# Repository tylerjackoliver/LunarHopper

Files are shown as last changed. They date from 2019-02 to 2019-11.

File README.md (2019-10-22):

# Lunar Hopper GitHub Repo

This is the repo for the Lunar Hopper on-board computer and control system.

## Test script usage
Tester file format:
*time (seconds) | command | arguments*

Tester file example:
```
0 start high
0.01 gyro 1 2
0.05 accel 1 2 3
0.1 throttle 50
0.27 press 90
1 abort high
5 disarm high
10 end
```

Test file example output:
```
-0.08030: ACT_PIN_X_POS reads 0
-0.08025: ACT_PIN_X_NEG reads 0
-0.08022: ACT_PIN_Y_POS reads 0
-0.06462: ACT_PIN_Y_NEG reads 0
-0.06457: SOL_PIN_VENT reads 0
-0.03106: SOL_PIN_PRES reads 0
-0.03098: SOL_PIN_OX reads 0
0.000371: 0 start high
0.012370: 0.01 gyro 1 2
0.085079: 0.05 accel 1 2 3
0.108033: 0.1 throttle 50
0.326400: 0.27 press 90
1.030022: 1 abort high
5.057830: 5 disarm high
10.06733: 10 end
10.10730: Test has concluded
```

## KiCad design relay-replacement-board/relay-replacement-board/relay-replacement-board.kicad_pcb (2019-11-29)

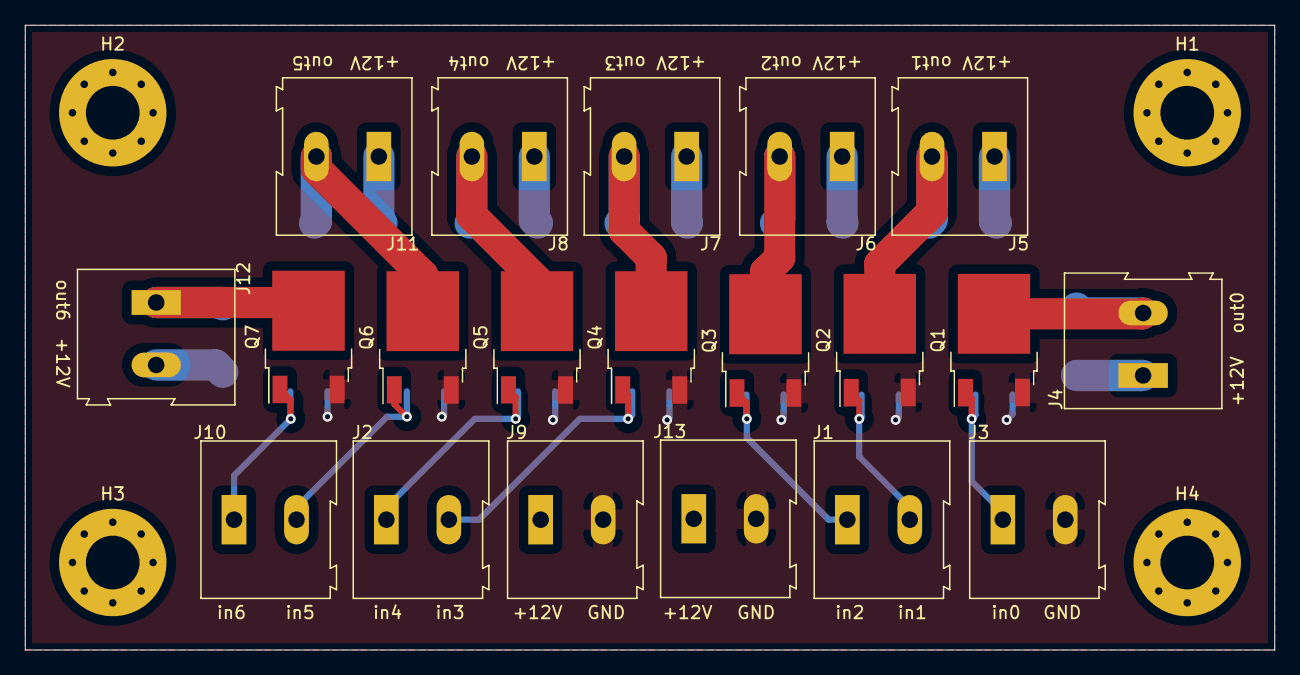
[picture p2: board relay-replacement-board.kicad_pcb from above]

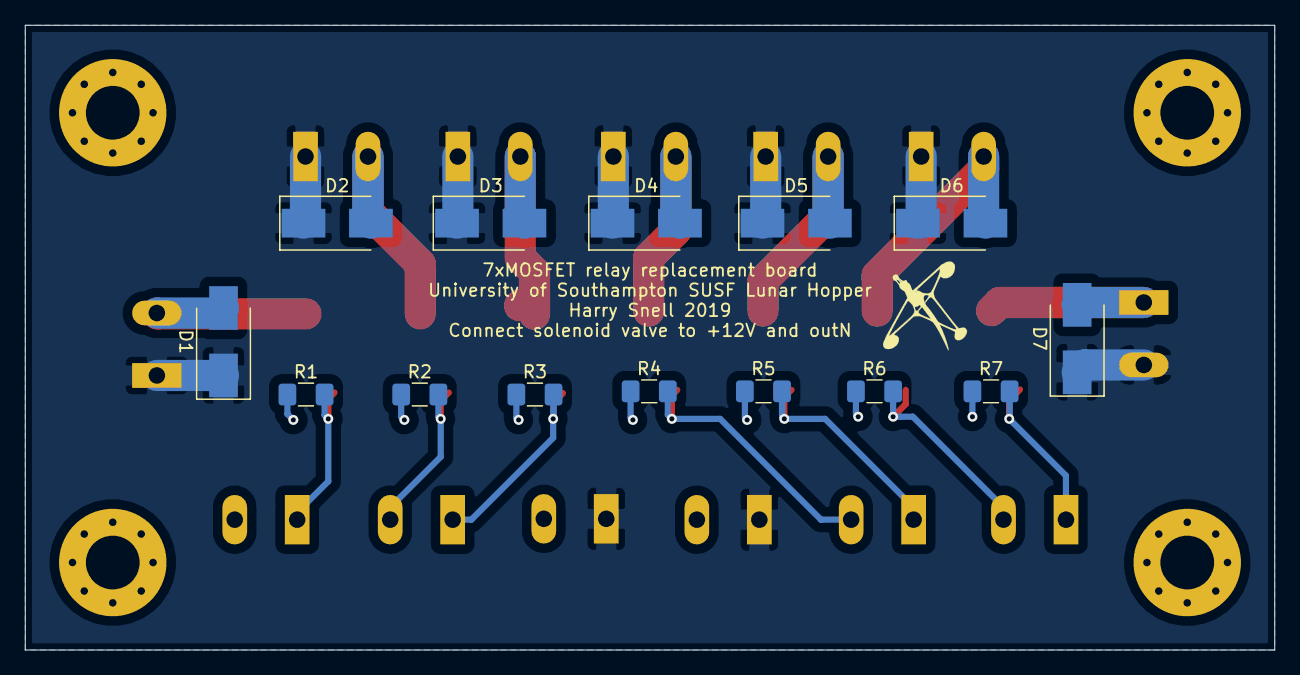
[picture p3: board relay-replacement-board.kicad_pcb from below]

Board: 2 copper layers, 100.0 x 50.0 mm, 38 parts (14 on the bottom side), 16 nets.

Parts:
D1, D2, D3, D4, D5, D6, D7: D; D_SMB_Handsoldering
H1, H2, H3, H4: MountingHole_4.3mm_M4_Pad_Via
J1, J2, J3, J4, J5, J6, J7, J8, J9, J10, J11, J12, J13: Conn_01x02; TerminalBlock_Altech_AK300-2_P5.00mm
Q1, Q2, Q3, Q4, Q5, Q6, Q7: NVD5865NL; TO-252-2
R1, R2, R3, R4, R5, R6, R7: 10K; R_1206_3216Metric_Pad1.42x1.75mm_HandSolder

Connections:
+12V: D1.1, D2.1, D3.1, D4.1, D5.1, D6.1, D7.1, J4.1, J5.1, J6.1, J7.1, J8.1, J9.1, J11.1, J12.2, J13.1
/trigger0: J3.1, Q1.1, R1.2
/trigger1: J1.2, Q2.1, R2.2
/trigger2: J1.1, Q3.1, R3.2
/trigger3: J2.2, Q4.1, R4.2
/trigger4: J2.1, Q5.1, R5.2
/trigger5: J10.2, Q6.1, R6.2
/trigger6: J10.1, Q7.1, R7.2
GND: J3.2, J9.2, J13.2, Q1.3, Q2.3, Q3.3, Q4.3, Q5.3, Q6.3, Q7.3, R1.1, R2.1, R3.1, R4.1, R5.1, R6.1, R7.1
unnamed: D1.2, J4.2, Q1.2
unnamed: D2.2, J5.2, Q2.2
unnamed: D3.2, J6.2, Q3.2
unnamed: D4.2, J7.2, Q4.2
unnamed: D5.2, J8.2, Q5.2
unnamed: D6.2, J11.2, Q6.2
unnamed: D7.2, J12.1, Q7.2

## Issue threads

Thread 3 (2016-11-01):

Rename Pins

bigboateng, 2016-11-01:
need to change the un-named pins when we know what they do. [Check this file](https://github.com/tylerjackoliver/LunarHopper/blob/master/Mk2.1_hopper_control.ino#L193-198)

tylerjackoliver, 2016-11-01:
Unnamed pins were renamed in commit c3c12a11de7ddbf1ebb9072c8c89a552c9bad47e.

bigboateng, 2016-11-01:
1. On the [Master Branch](https://github.com/tylerjackoliver/LunarHopper/blob/master/Mk2.1_hopper_control.ino#L193-198), the change is not there, which branch was that commit in?
2. Maybe we should actually rename the pins as variables because its still not clear what testing pins that is.

tylerjackoliver, 2016-11-01:
You're correct; the pins were commented out in the setup() of c3c12a11de7ddbf1ebb9072c8c89a552c9bad47e. Need to go through master and remove all references to pins 7, 8, 9, 24, 26, 28 as they are obsolete.

tylerjackoliver, 2016-11-01:
Need to verify code is still working after removing pin unnecessary pin references in commit cf2e08ffbd0063617e6673bff230312deaae3e4f in branch RemovedPins.

duncanrhamill, 2016-11-01:
Pins 7, 8 & 9 might be used for testing the ox pulse onto the catalyst bed, need to verify if they're needed in flight or just in test.

tylerjackoliver, 2016-11-02:
I spoke with Marian, who wrote the code: we had the right purpose for the pins and were correct to remove them in commit cf2e08ffbd0063617e6673bff230312deaae3e4f.

bigboateng, 2016-11-02:
So is this issue settled then? @tylerjackoliver

Closed 2016-11-02.

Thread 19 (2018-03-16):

Determine desired telemetry to design structure for a standard telemetry packet

tylerjackoliver, 2018-03-16:
To work on: https://github.com/tylerjackoliver/LunarHopper/projects/2#card-8045901

I'm going to take a look through the paperwork, and see exactly what telemetry we actually need back (or rather, what telemetry would be useful for debugging vehicle performance). That should let us know how long our packets need to be, and we can work on this from there.

cc: @shane-lawson

tylerjackoliver, 2018-03-16:
After going on a caffeine-fueled adventure, I think the only data we care about is the one that gives us our deltas from nominal performance, to be able to feedback into the ideal design spec. To that end, I think definitely we need to recover current pressure (if we are controlling it remotely, saving the pressure we set as well, or if it's on board, perhaps also grab desired pressure, so we can work out steady state errors and residual thrust problems), and also gyro rates. The current status of the vehicle also might be quite nice, i.e. ARM_HIGH, MECO_ON etc -- we can always dedicate a portion of each packet just to 1's and 0's that decide these values.

Just my first $.02...

shane-lawson, 2018-03-16:
100% agree with you about status of the various states, I was already thinking about maybe a byte or two header of bit values for on/off of various states.

For now I'll look at supporting:

- [ ] one byte with states
- [ ] current pressure value
- [ ] pressure set point
- [ ]     gyro rates
- [ ]     accel values (for good measure)

shane-lawson, 2018-11-01:
I initially created the branch `add-telemetry` to do this and I figured how everything worked. That code was really convoluted, so I forked `add-telemetry-final` from 58bd686a13075b064b94ddcac70d687cc5ce84ae as nothing after that commit in `add-telemetry` was useful anymore. This makes the `add-telemetry` branch functionally dead. I didn't merge it or rebase it onto `add-telemetry-final` as I thought that would make for a confusing history, so instead we'll probably just delete the `add-telemetry` branch.

In terms of accomplishing the above, the code currently just sends a single byte. I guess I never managed to create the logic for sending a string of bytes with all the above values. I plan on finishing that part and supporting all 5 things above. The `add-telemetry-final` branch is currently up-to-date, and I plan to make some nice documentation for it so others can make sense of how the telemetry transmission works, and how to set up an Arduino with an Xbee module to use this.

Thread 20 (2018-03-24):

Cross-check control laws

tylerjackoliver, 2018-03-24:
So, it seems that the control law that is currently implemented is a bit faulty with the angle determination, more than likely as a result of a badly-coded formula somewhere. AFAIK, it doesn't seem like the control laws were ever tuned either, given the '# this may need tweaking!!!'

@shane-lawson how feasible is it to just grab the quaternion/euler angles from the DMP on the 6050 and just plug this straight into their code in lieu of their angle determination code? A brief look at i2cdevlib seems to give the idea it's quite painless.

shane-lawson, 2018-03-24:
If all the DMP configuration code in that library works as specified, then we can _easily_ offload all the computation to the DMP and just pull the angles, etc. directly. I'm hesitant to ensure that this can be done easily, as there always seem to be finicky issues with things such as this that cause issues, the more simple appearing even more so.

The majority of the control code is doing the angle determination, there's just a gain or two that comes through fro the actual control. Pending a further review, we might determine it is easier to just implement, from scratch, the control law explored in the report using the DMP data.

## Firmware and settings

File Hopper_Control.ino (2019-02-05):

/*-------------------------------

Lunar Hopper Control System Code

Written by: Marian Daogaru, mn2g12

Updated by: Samuel Rowbotham      sjr1g18
            Jack Tyler            jt6g15
            Duncan Hamill         dh2g15
            Boateng Opoku-Yeboah  boy1g15
            Shane Lawson          sdl1n17
---------------------------------
*/

#include "Hopper_Control_Classes.cpp"

/*
 * DECLERATIONS
 */

/* PIN NUMBERS
 * Set pins for various input and output devices on arduino. e.g.- gyro, accelerometer,pressure transducer and solenoid valves.
 */
// Sensors (INPUTS)
const int PRES_TRANS_PIN = A4;  // Input from Pressure Transducer [ANALOG]
const int GYRO_PIN_X = A0;      // x-axis Gyro is connected to analog pin
const int GYRO_PIN_Y = A5;      // y-axis gyro
const int ACCEL_PIN_X = A1;     // x-axis accelerometer pin
const int ACCEL_PIN_Y = A2;     // y-axis accelerometer pin
const int ACCEL_PIN_Z = A3;     // z-axis accelerometer pin

// Actuators (OUTPUTS)
const int ACT_PIN_X_POS = 6;    // ACS valve positive x_axis
const int ACT_PIN_X_NEG = 5;    // ACS valve negative x_axis
const int ACT_PIN_Y_POS = 4;    // ACS valve positive y_axis
const int ACT_PIN_Y_NEG = 3;    // ACS valve negative y_axis
const int SOL_PIN_VENT = 12;    // Output to VENT solenoid control (SV2)
const int SOL_PIN_PRES = 10;    // Output to PRESSURE solenoid control (SV1)
const int SOL_PIN_OX = 11;      // Output to OX solenoid control(SV3)

// Control pins (INPUTS)
const int START_PIN = 30;
const int ABORT_PIN = 2;
const int DISARM_PIN = 1; // New pin to be added possibly
const int THROTTLE_PIN = A6;

// Valve constants for readability
const int VALVE_OPEN = HIGH;
const int VALVE_CLOSE = LOW;

/*
 * ACS
 */

// ACS configuration
unsigned long timeZG = 0;                      // Variable to record the start time of zeroing the gyros
unsigned long timeAcs = 0;                     // Variable used to record the start time of each ACS() loop
bool acsInCalibration = false;                 // Tracking variable to detect if ACS subsystem is active
bool acsCalibrated = false;                    // Tracking variable to record if ACS system has been acsCalibrated
bool midCycle = false;                         // Tracking variable to record if ACS system is mid Cycle

/*
 *  Main Engine
 */
// General
const float IGNITION_PRESSURE = 21.0; // bar (abs)
bool pressurised = false; // Records if the engine has been pressurised
bool ignited = false; // Records if the engine has been ignited

// oxPulse specific
int blipMode = 0;                            // Records the current mode of the oxPulse function (0: Ready to fire another blip, 1: Just fired a blip, 2: Just rested after a blip)
int oxPulseNo = 0;                           // Records the number of oxygen pulses completed (In Ignition)
unsigned long timePulse = 0;                 // Records the start time of the last ox blip


/*
 * System status
 * Used to record the current state of the hopper
 */
bool startStatus = false;                   // Records the state of the start pin to start the flight
bool disarmStatus = false;                  // Stores if the hopper has been disarmed
bool abortStatus = false;                   // Stores if the hopper has aborted
double currentPressure = 0;                 // Current pressre of the pressure transducer

// Initialisation of objects.
Accelerometer accelerometer;                // The accelerometers
Gyro gyro;                                  // The gyros
/*
 * CODE
 */

// Setup Loop
void setup() {
  Serial.begin(9600);
  Serial.println("Starting serial process...");
  pinMode(START_PIN, INPUT);      // Defines the Start pin as an INPUT
  pinMode(ABORT_PIN, INPUT);      // Defines the Abort pin as an INPUT
  pinMode(DISARM_PIN, INPUT);     // Defines the Disarm pin as an INPUT
  pinMode(THROTTLE_PIN, INPUT);   // Defines the Throttle as an INPUT
  pinMode(PRES_TRANS_PIN, INPUT); // Defines the Pressure Transducer reading as an INPUT
  pinMode(GYRO_PIN_X, INPUT);     // Defines the Gyro X reading as an INPUT
  pinMode(GYRO_PIN_Y, INPUT);     // Defines the Gyro Y reading as an INPUT
  pinMode(ACCEL_PIN_X, INPUT);    // Defines the Accelerometer X reading as an INPUT
  pinMode(ACCEL_PIN_Y, INPUT);    // Defines the Accelerometer Y reading as an INPUT
  pinMode(ACCEL_PIN_Z, INPUT);    // Defines the Accelerometer Z reading as an INPUT
  pinMode(ACT_PIN_X_POS, OUTPUT); // Defines the ACT positive X as an OUTPUT
  pinMode(ACT_PIN_X_NEG, OUTPUT); // Defines the ACT negative X as an OUTPUT
  pinMode(ACT_PIN_Y_POS, OUTPUT); // Defines the ACT positive Y as an OUTPUT
  pinMode(ACT_PIN_Y_NEG, OUTPUT); // Defines the ACT negative Y as an OUTPUT
  pinMode(SOL_PIN_VENT, OUTPUT);  // Defines the signal to Vent control as an OUTPUT
  pinMode(SOL_PIN_PRES, OUTPUT);  // Defines the signal to Pressure control as an OUTPUT
  pinMode(SOL_PIN_OX, OUTPUT);    // Defines the signal to OX control as an OUTPUT

  accelerometer.setPins(ACCEL_PIN_X,ACCEL_PIN_Y,ACCEL_PIN_Z);
  gyro.setPins(GYRO_PIN_X,GYRO_PIN_Y);
}

/*
 * Main execution loop
 */

void loop() {
  Serial.print("In loop:   ");
  Serial.println(timeZG);

  if (abortStatus == false) {
    Serial.println("ABORT status = false");
    if (disarmStatus == false) {
      if (startStatus == true) {
        Serial.println("Start = true");

        if (acsCalibrated == false) {
          Serial.println("Performing calibration...");
          acsCalibration();

        } else if (ignited == false) {
          Serial.print("oxPulseNo = ");
          Serial.println(oxPulseNo);
          oxPulse();
          
        } else {
          Serial.println("acs...");
          acs();
          Serial.println("throttle...");
          throttle();

        }
      } else {
        startStatus = digitalRead(START_PIN);
        Serial.println("Reading start pin...");

      }
      if (disarmStatus == false){ // Prevents disarm status from being overwritten
        disarmStatus = digitalRead(DISARM_PIN);

      }
      Serial.print("disarm status = ");
      Serial.println(disarmStatus);
    } else {
      disarm();

    }
  } else {
    abort();

  }
  if (abortStatus == false){ // Prevents abort status from being overwritten
      abortStatus = digitalRead(ABORT_PIN);

  }
  Serial.print("abort status = ");
  Serial.println(abortStatus);
}
  

/*
 * UPDATED TO LATEST VERSION 20/11/18 by Samuel Rowbotham
 *  Not Verified through system tests/simulations.
 *  Will slowly disarm the vehicle by having a gap between meco and ventAct
 */
void disarm() {
  const int ACT_VENT_DELAY = 5000; // 5 seconds between engine cut off and venting of act 
  disarmStatus = true;
  
  meco();

  delay(ACT_VENT_DELAY);
  ventAct();
}

/*
 * UPDATED TO LATEST VERSION 20/11/2018 by Samuel Rowbotham
 * Not Verified through system tests/simulations.
 * Instantly shutsoff the engine and vents the ACT
   The codes were therefore tested using the simulation function in the Xojo App which simulates the MECO remote being on/off and the hopper being armed/disarmed.
 */

void abort() { // Rename to abort for visual
  Serial.println("ABORTING");
  abortStatus = true;
  
  meco();
  ventAct();
}

// Vents the ACS
void ventAct() {
  Serial.println("Venting ACT");
  digitalWrite(ACT_PIN_X_POS, VALVE_OPEN);
  digitalWrite(ACT_PIN_X_NEG, VALVE_OPEN);
  digitalWrite(ACT_PIN_Y_POS, VALVE_OPEN);
  digitalWrite(ACT_PIN_Y_NEG, VALVE_OPEN);
}

void meco() {
  digitalWrite(SOL_PIN_OX, VALVE_CLOSE);
  digitalWrite(SOL_PIN_PRES, VALVE_CLOSE);
  digitalWrite(SOL_PIN_VENT, VALVE_OPEN);
}

/*acsCheck()--checks the commands related to the ACS and runs the appropriate routine.
 *-------------Uses sub functions- ACS and acsCalibration
 *-------------Also performs tasks relating to venting and ACT test.
 *acsCalibration()-- Performs calibration for given calibration time
 *acs()--The main function housing the control law for the hopper.
 *-------Calculates current angles from gyro and accelerometers, applies complementary filtering
 *-------Uses the control law to regulate the ACT solenoid valves
 *
 *
 *Original Author: Zhihan Ma
 *Modified, updated and verified by Achal Mittal
 *NOT to be changed without approval from both Zhihan Ma and Achal Mittal
 */

void acsCalibration() {
  const unsigned long  CALIBRATION_TIME = 40000; // Time used to zero the gyro

  if (acsInCalibration == false){
    acsCalibrated = false;
    accelerometer.reset();
    gyro.reset();
    acsInCalibration = true;
    timeZG = millis();      //start zeroing time
    Serial.print("Checking, timeZG = ");
    Serial.println(timeZG);
  }
  
  if (timeZG + CALIBRATION_TIME > millis()) { // If calibration time is not over
    accelerometer.addCalibrationValue();
    gyro.addCalibrationValue();
    Serial.print("Still calibrating at elapsed time: ");
    Serial.println(timeZG + CALIBRATION_TIME-millis());

  } else {
    if (acsCalibrated == false) {  // If calibration time has just finished
      accelerometer.finaliseCalibration(); // Calculate the zero voltages for the accelerometer
      gyro.finaliseCalibration(); // Calculate the zero voltage for the gyroscope
      acsCalibrated = true;      // Record calibration has finished
    }
  }
}

// Calculates the angle of the hopper and activates the ACT in response. If the angle is greter then MAX_ANGLE it abort's.
void acs() {
  const unsigned long TIME_INTERVAL = 25; // Time in milliseconds between each adjustment of the ACS system
  const float CFF_VECTOR_GYRO = 0.90; // Complementary filter- choose what percentage of gyro angle you want in the final angle.
  const float CFF_VECTOR_ACCEL = 0.10; // Complementary filter- choose what percentage of accelerometer angle you want in the final angle.
  const float CONTROL_LAW_GAIN = 0.5; // Gain of control law

  if (midCycle == false) { // If midCycle starting for first time or has just finished
    midCycle = true; // Record the midCycle is starting
    timeAcs = millis(); // Record the start time of the midCycle
    gyro.setTimeAcs(timeAcs);

  } else if (timeAcs + TIME_INTERVAL < millis()) { // If time interval has passed
    midCycle = false;
    
    // Calculate angular rates and integrate for angle
    accelerometer.calcAngles();
    gyro.calcAngles();

    float currentAngleX = CFF_VECTOR_GYRO * gyro.getAngleX() + CFF_VECTOR_ACCEL * accelerometer.getAngleX(); // Apply complementary filtering in z axis
    float currentAngleY = CFF_VECTOR_GYRO * gyro.getAngleY() + CFF_VECTOR_ACCEL * accelerometer.getAngleY(); // Apply complementary filtering in y axis

    float nextAngleX = currentAngleX + CONTROL_LAW_GAIN * gyro.getRateX();
    float nextAngleY = currentAngleY + CONTROL_LAW_GAIN * gyro.getRateY();

    acsThrustControl(ACT_PIN_X_POS, ACT_PIN_X_NEG, nextAngleX, "X");
    acsThrustControl(ACT_PIN_Y_POS, ACT_PIN_Y_NEG, nextAngleY, "Y");
    
  }
  // delay(10);
}

void acsThrustControl(int PIN_POS, int PIN_NEG, float nextAngle, char dir) {
  const int MAX_ANGLE = 15; // This angle will trigger abort
  const float CONTROL_LAW_DEADBAND = 0.1; // Threshold for control law (deadband) #maybe this is a bit too low, might require some changes

  Serial.print("nextAngle");
  Serial.print(dir);
  Serial.print(" = ");
  Serial.println(nextAngle);
  if (abs(nextAngle) < MAX_ANGLE) {
    if (abs(nextAngle) >= CONTROL_LAW_DEADBAND) {
      if (nextAngle > 0) {    // Control law
        digitalWrite(PIN_POS, VALVE_OPEN);
        digitalWrite(PIN_NEG, VALVE_CLOSE);

      } else if (nextAngle < 0) {
        digitalWrite(PIN_POS, VALVE_CLOSE);
        digitalWrite(PIN_NEG, VALVE_OPEN);
      
      }
    } else {
      digitalWrite(PIN_POS, VALVE_CLOSE);
      digitalWrite(PIN_NEG, VALVE_CLOSE);
    }
  } else {
    abort();
  }
}

// Blips the OX to warm up the catalyst bed (Effective igniton)
void oxPulse() {
  const unsigned long BLIP_DURATION = 300; // Time in milliseconds the ox pulse lasts
  const unsigned long BLIP_REST_DURATION = 5000; // Duration for which the system will wait for heat to dissipare in the fuel
  const int OX_NO_PULSES = 3;

  pressurisation();

  if (pressurised == true) {
    if (blipMode == 0) { // Ready to fire another blip
      timePulse = millis();
      digitalWrite(SOL_PIN_OX, VALVE_OPEN);
      blipMode = 1;

    } else if (blipMode == 1 && timePulse + BLIP_DURATION < millis()) { // Just fired a blip
      digitalWrite(SOL_PIN_OX, VALVE_CLOSE);
      blipMode = 2;
      timePulse = millis();

    } else if (blipMode == 2 && timePulse + BLIP_REST_DURATION < millis()) { // Just rested after a blip
      blipMode = 0;
      oxPulseNo++;
    }
  }
  if (oxPulseNo >= OX_NO_PULSES) {
    ignited = true;
  }
}

// Pressurises the solonoid prior to oxPulse (ignition)
void pressurisation() {
  currentPressure = getPressure();

  Serial.print("Current pressure = ");
  Serial.println(currentPressure);

  if (currentPressure < IGNITION_PRESSURE) {
    digitalWrite(SOL_PIN_PRES, VALVE_OPEN);
    pressurised = false;

  } else {
    digitalWrite(SOL_PIN_PRES, VALVE_CLOSE);
    pressurised = true;
  }
}

// Throttle control of the vehicle (controled manually)
void throttle() {
  currentPressure = getPressure();

  float throttlePressure = ((analogRead(THROTTLE_PIN) / 1023 * 21 )) + 19;
  Serial.print("Throttle pressure = ");
  Serial.println(throttlePressure);
  Serial.print("Current pressure = ");
  Serial.println(currentPressure);

  if (currentPressure < IGNITION_PRESSURE ) {
    digitalWrite(SOL_PIN_PRES, VALVE_OPEN);
    digitalWrite(SOL_PIN_OX, VALVE_CLOSE);
    Serial.println("current < ig");

  } else if (throttlePressure >= currentPressure && currentPressure > IGNITION_PRESSURE) {
    digitalWrite(SOL_PIN_PRES, VALVE_OPEN);
    digitalWrite(SOL_PIN_OX, VALVE_OPEN);
    Serial.println("throttle >= current && current > ig");

  } else if (throttlePressure < IGNITION_PRESSURE && IGNITION_PRESSURE < currentPressure) {
    digitalWrite(SOL_PIN_PRES, VALVE_CLOSE);
    digitalWrite(SOL_PIN_OX, VALVE_CLOSE);
    Serial.println("throttle < ig < current");

  } else if (throttlePressure < currentPressure && IGNITION_PRESSURE < currentPressure && IGNITION_PRESSURE < throttlePressure) {
    digitalWrite(SOL_PIN_PRES, VALVE_CLOSE);
    digitalWrite(SOL_PIN_OX, VALVE_OPEN);
    Serial.println("ig < throttle < current");

  }
}

// Returns the pressure in bars of the Pressure Transducer
double getPressure() {
  int voltage = analogRead(PRES_TRANS_PIN);
  return voltage * (40 / 1023); //int * (bar/int) returns: bar
}

// Not used currently resets all values
void reset() {
  timeZG = 0;
  acsInCalibration = false;
  acsCalibrated = false;
  midCycle = false;
  timeAcs = 0;
  blipMode = 0;
  oxPulseNo = 0;
  timePulse = 0;
  currentPressure = 0;
  pressurised = false;
  startStatus = false;
  disarmStatus = false;
  abortStatus = false;
}

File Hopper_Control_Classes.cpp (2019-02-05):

#include "Arduino.h"
// Classes
class Accelerometer {
  public:

  	// Sets the pins of the accelerometer
    setPins(int pinX, int pinY, int pinZ) {
      PIN_X = pinX;
      PIN_Y = pinY;
      PIN_Z = pinZ;
    }

    // Calculates the current angle of the accelerometer
    void calcAngles() {
      const float ACCEL_SENSITIVITY = 0.8;
      float zeroVoltZ = 1.775;

      float x_g = ((analogRead(PIN_X) * VCC / 1023.00) - zeroVoltX) / ACCEL_SENSITIVITY;
      float y_g = ((analogRead(PIN_Y) * VCC / 1023.00) - zeroVoltY) / ACCEL_SENSITIVITY;
      float z_g = ((analogRead(PIN_Z) * VCC / 1023.00) - zeroVoltZ) / ACCEL_SENSITIVITY;
      float c_g = sqrt(sq(y_g) + sq(z_g));  // Calculate the gravity using y and z axis
      float d_g = sqrt(sq(x_g) + sq(z_g));  // Same as above using x and y axis
      float accAngleInRadiansX = -atan2 (x_g, c_g);
      float accAngleInRadiansY = -atan2 (y_g, d_g);
      angleX = accAngleInRadiansX * 180 / M_PI;  // Get x-angle from accelerometer in degrees
      angleY = accAngleInRadiansY * 180 / M_PI;  // Get y-angle from accelerometer in degrees
    }


    // Resets the accelerometer
    void reset() {
   	  calibrated = false;
      acquisitionsCount = 0;
      voltageSumX = 0;
      voltageSumY = 0;
    }

    // Calculate the final variables
    void finaliseCalibration() {
      zeroVoltX = (voltageSumX * VCC) / (acquisitionsCount * 1023);
      zeroVoltY = (voltageSumY * VCC) / (acquisitionsCount * 1023);
      calibrated = true;
    }

    // Add one set of calibration numbers
    void addCalibrationValue() {
      voltageSumX += analogRead(PIN_X);
      voltageSumY += analogRead(PIN_Y);
      acquisitionsCount++;
    }

    // Getter for calibrated
    bool isCalibrated() {
      return calibrated;
    }

    // Getter for angleX
    float getAngleX() {
      return angleX;
    }

    // Getter for angleY
    float getAngleY() {
      return angleY;
    }

  private:
    const float VCC = 5.0; // Stores the base voltage of the VCC

    int PIN_X; // Stores the accelerometer's X pin
    int PIN_Y; // Stores the accelerometer's Y pin
    int PIN_Z; // Stores the accelerometer's Z pin

    bool calibrated = false; // Stores if the accelerometer is calibrated

    int acquisitionsCount; // Number of calibration values taken

    float voltageSumX; // Sum of accelerometers X calibration Values
    float voltageSumY; // Sum of accelerometers Y calibration Values

    float zeroVoltX; // Calibrated zero voltage of the accelerometer X
    float zeroVoltY; // Calibrated zero voltage of the accelerometer Y
    
    float angleX; // Accelerometers current angle in the x axis
    float angleY; // Accelerometers current angle in the Y axis
};


class Gyro {
  public:

    // Sets the pins of the gyro
    setPins(int pinX, int pinY) {
      PIN_X = pinX;
      PIN_Y = pinY;
    }

    // Calculates the current angles of the gyros and their rate of change
    void calcAngles() {
      const float GYRO_SENSITIVITY = 0.04;

      int samplingCount = 0; 
      float sumX = 0.0; 
      float sumY = 0.0;
      // Get reading ten times-over sampling to reduce noise
      for (samplingCount = 0;samplingCount < 10; samplingCount++) {
        sumX += analogRead(PIN_X); // Add current Z gyro voltage to running total
        sumY += analogRead(PIN_Y);
      }

      //
      // Below formula is based on the orientaiton that the gyro is mounted. Need to be careful when mounting
      rateX = ( (sumX * VCC) / (samplingCount * 1023.) - zeroVoltX) / GYRO_SENSITIVITY * (1.0); // Calculate if any movement has occured in the X axis and correct angle (change sign due to how the gyro is mounted on the frame)
      rateY = ( (sumY * VCC) / (samplingCount * 1023.) - zeroVoltY) / GYRO_SENSITIVITY * (1.0); // Same for y axis
      //
      //

      angleX = rateX * (millis() - timeAcs + 15.00) * 0.001;  // Get x angle from x-axis gyro
      angleY = rateY * (millis() - timeAcs + 15.00) * 0.001;  // Get y angle from y-axis gyro
    }

    // Resets the gyro
    void reset() {
      calibrated = false;
      acquisitionsCount = 0;
      voltageSumX = 0;
      voltageSumY = 0;
    }

    // Calibrates the zeroVoltage of its X and Y angles
    void finaliseCalibration() {
      zeroVoltX = (voltageSumX * VCC) / (acquisitionsCount * 1023);
      zeroVoltY = (voltageSumY * VCC) / (acquisitionsCount * 1023);
      calibrated = true;
    }

    // Adds a calibration value to the gyro's sum
    void addCalibrationValue() {
      voltageSumX += analogRead(PIN_X);
      voltageSumY += analogRead(PIN_Y);
      acquisitionsCount++;
    }

    // Getter for angleX
    float getAngleX() {
      return angleX;
    }

    // Getter for angleY
    float getAngleY() {
      return angleY;
    }

    // Getter for rateX
    float getRateX(){
      return rateX;
    }

    // Getter for rateY
    float getRateY(){
      return rateY;
    }
    
    // Sets the last time the ACS corrected the hoppers orientation
    void setTimeAcs(unsigned long time){
      timeAcs = time;
    }

  private:

    const float VCC = 5.0; // Stores the base voltage of the VCC
        
    int PIN_X; // Gyro X pin
    int PIN_Y; // Gyro Y pin

    bool calibrated = false; // Stores if the gyro is calibrated

    int acquisitionsCount; // Number of calibration values taken

    float voltageSumX; // Sum of gyro X calibration Values
    float voltageSumY; // Sum of gyro Y calibration Values

    float zeroVoltX; // Calibrated zero voltage of the gyro X
    float zeroVoltY; // Calibrated zero voltage of the gyro Y
    
    float angleX; // Gyros current angle in the x axis
    float angleY; // Gyros current angle in the Y axis

    float rateX; // Gyros current rate of change in the x axis
    float rateY; // Gyros current rate of change in the y axis

    unsigned long timeAcs = 0; // The last time the ACS corrected the hoppers orientation
};

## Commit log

2016-10-28 Refactored ledpinN => ACS(direction) for readability
2016-11-01 Removes unnecessary pin references in HopperControl.c
2018-02-28 Change to const pin declarations and rename accordingly
    Following standard ALL_CAPS for names of constants.
    Names are created for pins first by description, then pin, followed by
    identifier (eg. SOL_PIN_VENT) where descriptions are:
    ACCEL - accelerometer
    ACT - attitude control thruster
    GYRO - gyroscope
    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
2018-02-28 Create constants for valve HIGH/LOW toggles
    Aptly named VALVE_ON and VALVE_OFF for lots of swish readability
2018-02-28 Resolve inconsistencies with valve statuses in disarm()
    Follow on of 987777d10436639d3124edaab32d6d8bb942d07a
    Another hunch, I think we want the vent valve open, to relieve pressure in
    fuel feed system.
    Assuming, just based on my previous status reasoning, that we want
    passivation of the entire system, therefore we want to vent pressure in
    the ACS as well. However, the big issue here is that the only way to
    vent the ACS is to turn on the thrusters, which sounds a bit less
    ideal, like a flopping fish (more potential damage and damage of
    rupture, etc.)
2018-03-01 Implement calculation of current pressure
    The existing calculation return 1 to 40 bar, the new
    one correctly returns 0 to 40 bar.
    Calculation also implemented in function so that it
    can be called from anywhere in the program without
    doing so explicity (previous method).
2018-03-07 Create merged_lunar_hopper_code
    Merged Shane's functions with main loop code.
    I left out the calibration in the main loop as I'm assuming it's going to be used with a gyroscope so it will only need to be calibrated once which I have put in the setup().
2019-10-22 Create Tester.py
    Test script for a pi to interface with the arduino. Specific DAC controll to be implemented.
2019-11-23 Create eCAD files for relay replacement files
    [relay-replacement-board.kicad_pcb, relay-replacement-board.sch]
2019-11-23 Placement of components on board
    [relay-replacement-board.sch]
2019-11-23 Trace routing
    [relay-replacement-board.kicad_pcb, relay-replacement-board.sch]
2019-11-23 M4 mounting holes
    [relay-replacement-board.kicad_pcb]
2019-11-23 added extra +12V in
    The rated current on the terminal blocks is 16A each which is less than the possible current draw if every valve were on at the same time. This change increases the current capacity to and from the +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
    [relay-replacement-board.kicad_pcb]
2019-11-23 Minor adjustments to trace routing
    [relay-replacement-board.kicad_pcb, relay-replacement-board.sch]
2019-11-23 routing changes
    [relay-replacement-board.kicad_pcb]
2019-11-23 Added flyback diodes
    These protect the MOSFETs when they switch off. PCB also reorganised and shrunk slightly to 10*5cm
    [relay-replacement-board.kicad_pcb, relay-replacement-board.sch]
2019-11-23 Added M4 mounting holes
    THese are not currently connected to Ground but could be
    [relay-replacement-board.kicad_pcb]
2019-11-24 Added silkscreen
    Text explaining what to connect where on the board
    [relay-replacement-board.kicad_pcb]
2019-11-24 change silkscreen orientation
    [relay-replacement-board.kicad_pcb]
2019-11-29 Added team logo to back silkscreen
    [relay-replacement-board.kicad_pcb]
2019-11-29 Gerber file export
    exported Gerber files as required by Elecrow for manufacturing
    [relay-replacement-board-B_Cu.gbl, relay-replacement-board-B_Mask.gbs, relay-replacement-board-B_SilkS.gbo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]
2019-11-29 Final exit
    [relay-replacement-board.kicad_pcb]
